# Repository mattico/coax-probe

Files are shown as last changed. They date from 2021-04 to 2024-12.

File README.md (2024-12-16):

# Coax Probes

**⚠️ NOTE:** I designed this as a learning experience. I never tested it very much, don't expect it to work well. In particular note [the limited common mode voltage range of the INA128](https://github.com/mattico/coax-probe/issues/1) which means this probe can't properly measure anything below 2V.

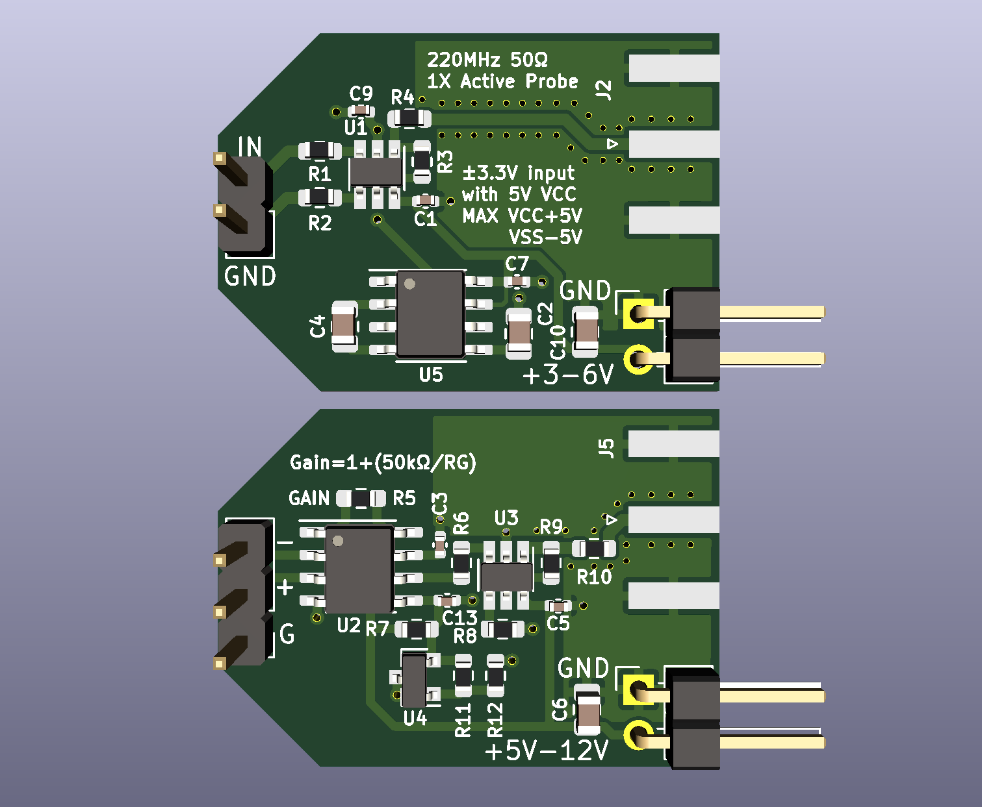
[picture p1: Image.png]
PCB Render


Simple, cheap, nearly disposable active electronic probes.

See the `lmh6642` branch for an even cheaper version with less bandwidth.

## License

Licensed under the terms of the *CERN Open Hardware Licence Version 2 - Weakly Reciprocal* see [the LICENSE file](LICENSE) for details.

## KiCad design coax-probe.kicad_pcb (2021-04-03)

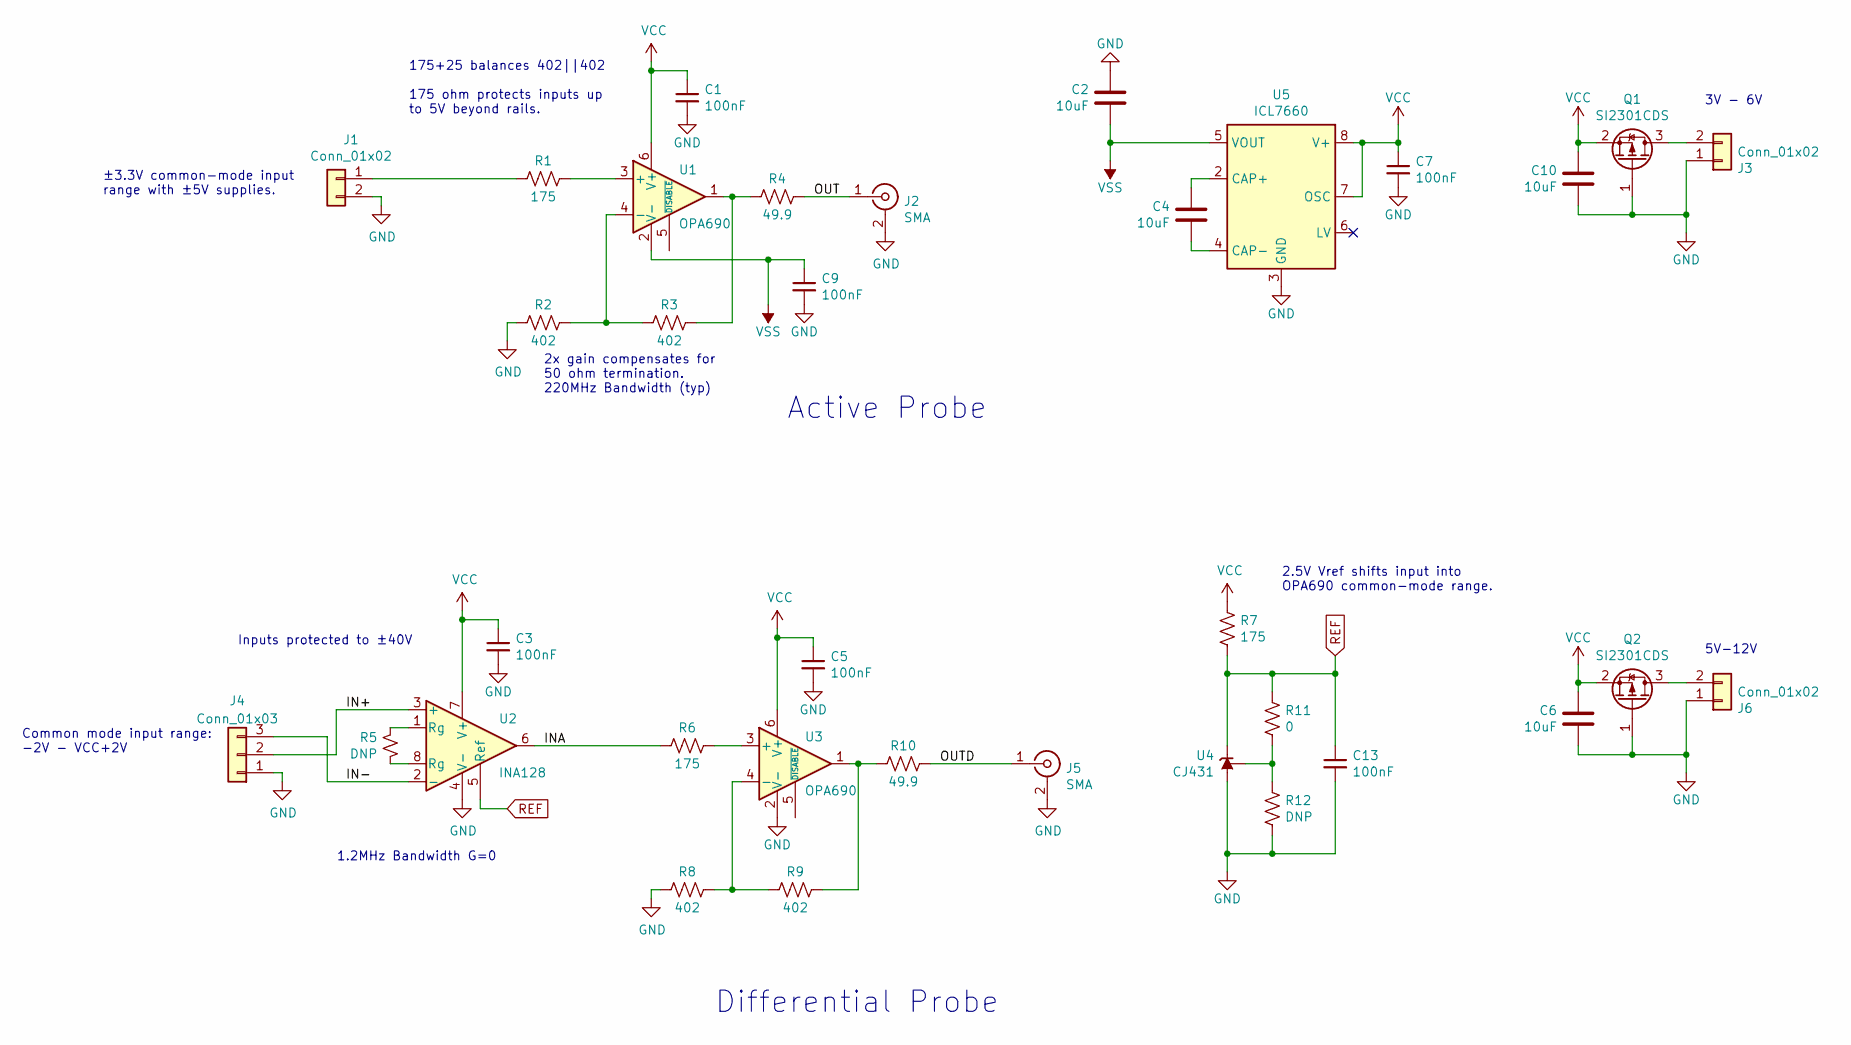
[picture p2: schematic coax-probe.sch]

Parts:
C1, C3, C5, C7, C9, C13: 100nF; C_0402_1005Metric; MPN CL05B104KO5NNNC; LCSC C1525
C2, C4, C6, C10: 10uF; C_0805_2012Metric; MPN CL21A106KAYNNNE; LCSC C15850
J1: Conn_01x02; PinHeader_1x02_P2.54mm_Vertical
J2, J5: SMA; SMA_Amphenol_132289_EdgeMount
J3, J6: Conn_01x02; PinHeader_1x02_P2.54mm_Horizontal
J4: Conn_01x03; PinHeader_1x03_P2.54mm_Vertical
Q1, Q2: SI2301CDS; SOT-23; LCSC C10487
R1, R6, R7: 175; R_0603_1608Metric; LCSC C22828
R2, R3, R8, R9: 402; R_0603_1608Metric; LCSC C23049
R4, R10: 49.9; R_0603_1608Metric; LCSC C23185
R5: DNP; R_0603_1608Metric_Pad0.98x0.95mm_HandSolder
R11: 0; R_0603_1608Metric; LCSC C21189
R12: DNP; R_0603_1608Metric
U1, U3: OPA690; TSOT-23-6; MPN OPA690IDBVT; LCSC C206074
U2: INA128; SOIC-8_3.9x4.9mm_P1.27mm; LCSC C22233
U4: CJ431; SOT-23; LCSC C3113
U5: ICL7660; SOIC-8_3.9x4.9mm_P1.27mm; LCSC C7881

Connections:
/IN+: J4.2, U2.3 (+)
/IN-: J4.3, U2.2 (-)
/INA: R6.2, U2.6
/OUT: J2.1 (In), R4.1
/OUTD: J5.1 (In), R10.1
GND: C1.2, C2.1, C3.2, C5.2, C6.1, C7.2, C9.2, C10.1, C13.2, J1.2, J2.2 (Ext), J3.1, J4.1, J5.2 (Ext), J6.1, Q1.1 (G), Q2.1 (G), R2.2, R8.2, R12.2, U2.4 (V-), U3.2 (V-), U4.3 (A), U5.3 (GND)
unnamed: C4.1, U5.2 (CAP+)
unnamed: C4.2, U5.4 (CAP-)
unnamed: J1.1, R1.2
unnamed: J3.2, Q1.3 (D)
unnamed: J6.2, Q2.3 (D)
unnamed: R1.1, U1.3 (+)
unnamed: R2.1, R3.2, U1.4 (-)
unnamed: R3.1, R4.2, U1.1
unnamed: R5.1, U2.8 (Rg)
unnamed: R5.2, U2.1 (Rg)
unnamed: R6.1, U3.3 (+)
unnamed: R8.1, R9.2, U3.4 (-)
unnamed: R9.1, R10.2, U3.1
unnamed: R11.2, R12.1, U4.1 (REF)
REF: C13.1, R7.2, R11.1, U2.5 (Ref), U4.2 (K)
VCC: C1.1, C3.1, C5.1, C6.2, C7.1, C10.2, Q1.2 (S), Q2.2 (S), R7.1, U1.6 (V+), U2.7 (V+), U3.6 (V+), U5.7 (OSC), U5.8 (V+)
VSS: C2.2, C9.1, U1.2 (V-), U5.5 (VOUT)

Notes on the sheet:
Differential Probe
5V-12V
Inputs protected to ±40V
Common mode input range: -2V - VCC+2V
1.2MHz Bandwidth G=0
Active Probe
2x gain compensates for 50 ohm termination. 220MHz Bandwidth (typ)
175+25 balances 402||402 175 ohm protects inputs up to 5V beyond rails.
3V - 6V
±3.3V common-mode input range with ±5V supplies.
2.5V Vref shifts input into OPA690 common-mode range.

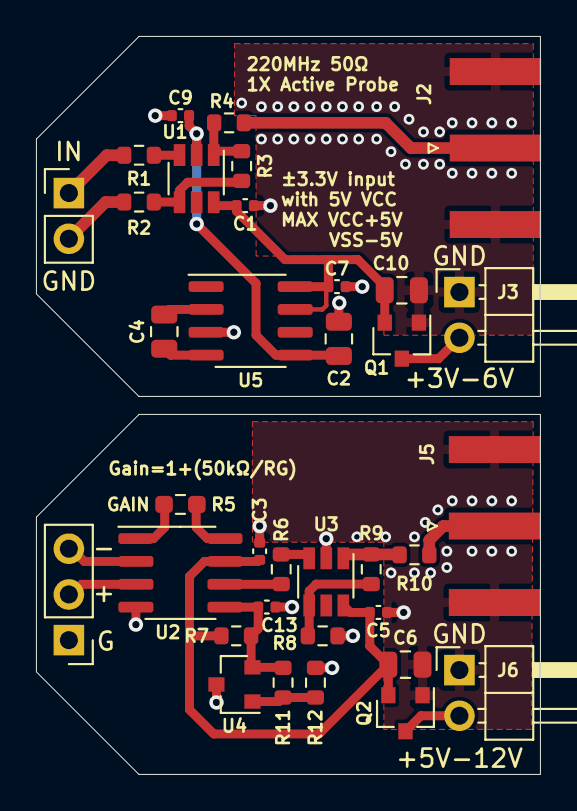
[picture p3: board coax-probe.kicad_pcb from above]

Board: 2 copper layers, 28.0 x 41.0 mm, 35 parts (0 on the bottom side), 23 nets.

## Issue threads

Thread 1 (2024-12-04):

INA128 can't hanle 0V-2V Vin- when using single-supply

Zak0nCh1ps, 2024-12-04:
Thank you very much for your open-source project.

I am currently working on an portable audio player hardware. Due to the large number of MLCCs placed on the PCB, I need to pay attention to the inrush current on the power rails to prevent any issues.

My approach is to place a current sensing resistor on the power rail, lead it out to a Header on the board edge, and then use an external differential probe to measure the voltage across the resistor. The true low-voltage differential probes with gain are too expensive, so I discovered your project and immediately began working on it. (There are some soldering messes and poorly fitting connectors, ignore them.)

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

I don't have a particularly good method to test the probe's bandwidth, but since the bandwidth of the INA128 is not  high, I estimated it by measuring the rise time of the GPIO on an STM32 Nucleo board. According to the manual, the GPIO rise time is approximately a few nanoseconds. On the probe, with RG = NC, meaning a gain of 1, I obtained a rise time of about 500ns (200ns/div on picture), which corresponds to a bandwidth of 700kHz (lower than the 1.2MHz specified in the manual). I'm not sure if my method is correct.

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

However, the output voltage is completely incorrect.

I tried removing the probe and directly measuring the VO of the INA128 with a multimeter.

With VIN- and G connected to GND, when VIN+ is 1.8V, the output is 3.2V; when VIN+ is 3.3V, the output is 4.7V; and when VIN+ is 5V, the output is 6.4V. There is a strange 1.4V offset.

At first, I suspected that the VREF was problematic, but measurements showed that VREF was accurately 2.5V. Additionally, I noticed that although the BOM specifies the CJ431, the pinout of the package is actually that of the TL431, which has a different pin order. However, since the two pins are connected by a 0-ohm resistor, this is not an issue.

I cannot understand what is happening.

Eventually, only when I connected VIN- to 3.3V and VIN+ to 5V, did I get the correct Vo, which is ((VIN+) - (VIN-)) * Gain + Vref = (5-3.3)*1 + 2.5 = 4.2V.

Later, I discovered that the input common-mode voltage range of the INA128 is from VNeg + 2V to VPos - 2V. For single-supply operation, this means that its VIN- minimum input is +2V, so it cannot handle signals between 0V and 2V correctly.

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

It seems that for power measurement purposes, this differential probe should always use dual-supply operation?

mattico, 2024-12-16:
Hey, good catch! I hope I didn't waste too much of your time.

I put this project together when I was trying to teach myself analog electronics, so it's not surprising I missed something obvious like that. I don't think I ever expected anyone else to really see this repo. I'll add a note to that effect in the readme.

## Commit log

2021-03-31 use dual-supply for differential amp buffer
    [coax-probe.kicad_pcb, coax-probe.sch]
2021-03-31 Improvements, layout
    [coax-probe.kicad_pcb, coax-probe.sch]
2021-04-02 Add charge pump. Improve layout.
    [coax-probe.kicad_pcb, coax-probe.sch]
2021-04-02 Layout tweaks
    [coax-probe.kicad_pcb]
2021-04-02 Fix 50-ohm trace width
    [coax-probe.kicad_pcb, coax-probe.sch]
2021-04-02 Use SMA connectors
    [coax-probe.kicad_pcb, coax-probe.sch]
2021-04-02 Tweak zones.
    [coax-probe.kicad_pcb]
2021-04-03 Space out Vref more
    [coax-probe.kicad_pcb]
2021-04-03 Widen PCBs for JLC assembly service
    [coax-probe.kicad_pcb, coax-probe.sch]
2021-04-03 Add fab outputs and part numbers
    [coax-probe-B_Cu.gbr, coax-probe-B_Mask.gbr, coax-probe-B_Paste.gbr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]
2021-04-03 Add power reverse-polarity protection
    [coax-probe.kicad_pcb, coax-probe.sch]
